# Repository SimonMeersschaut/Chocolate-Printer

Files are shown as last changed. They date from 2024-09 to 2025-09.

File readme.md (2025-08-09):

# Chocolate Printer

## About

This project focuses on modifying a 3D printer to create chocolate sculptures. Achieving this required changes to both the hardware and software. This repository contains all the information you need to replicate the setup yourself.

## Documentation

For extensive documentation, please refer to the pdf file `documentation/main.pdf`. We chose not to include this file in the source code, so you will have to compile the pdf yourself.

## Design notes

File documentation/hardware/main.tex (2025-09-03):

\subsection{Stepper Motor}

\begin{tabular}{@{}ll}
    \textbf{Type:} & Creality CR - M4 42-34 Motor \\
    \textbf{Voltage:} & Max 1A \\
    \textbf{Current Range:} & Ideally 0.9A - 1.2A (Motor cracking sound below this range) \\
    \textbf{Current Range:} & 0.3A to 2.5A (Source: \url{https://www.youtube.com/watch?v=7spK_BkMJys}) \\
    \textbf{Holding Torque:} & 2.86 kg.cm Type \\
\end{tabular}

\subsection{Stepper Motor Driver}

\textbf{Old Stepper Motor Driver}

\begin{tabular}{@{}ll}
    \textbf{Type:} & A4988 \\
    \textbf{Recommended Current:} & Max 1A \\
    \textbf{Microstepping:} & \\
\end{tabular}

\noindent
\textbf{New Stepper Motor Driver}

\begin{tabular}{@{}ll}
    \textbf{Type:} & TMC2208? \\
\end{tabular}

% \includegraphics[width=0.7\textwidth]{image.png}

\subsection{Arduino CNC Shield}

\begin{tabular}{@{}ll}
    \textbf{Type:} & Arduino Mega CNC shield: RAMPS 1.4  \\
    \textbf{Url:} & \url{https://www.manomano.fr/p/3d-controleur-dimprimante-ramps-14-mega-shield-pour-arduino-reprap-prusa-mendel-86220892} \\
    \textbf{Docs:} & \url{https://reprap.org/wiki/RAMPS_1.4}
\end{tabular}

In order to run pn 24 volt, you have to disconnect the board from the ardiono Mega by removing a diode.
This is explained in detail here: \url{https://reprap.org/wiki/RAMPS_24v}.

\subsection{Temperature Sensor}

\textbf{Type:} NTC 10K, B57164 - K103 - K

\textbf{Resistance Values:}
\begin{itemize}
    \item 25$^\circ$C: Approximately 6,000 Ohm
    \item 50$^\circ$C: Approximately 2,000 Ohm (Target: 1,000 Ohm).  A parallel resistor of 2 kOhm is needed.
\end{itemize}

\subsection{Leadscrew, Nut, and Coupler}

\textbf{Nut:} \url{https://www.123-3d.nl/123-3D-Leadscrew-moer-TR8x8-i1560-t9712.html}

\textbf{Coupler:} \url{https://www.123-3d.nl/123-3D-Flexibele-motor-koppeling-5-mm-8-mm-i342-t3045.html}

\textbf{Leadscrew:} \url{https://www.123-3d.nl/123-3D-Leadscrew-TR8x8-8-mm-30-cm-i1558-t9712.html}

\textbf{Heating Wire:} \url{https://www.amazon.com.be/-/en/Meter-Silicone-Rubber-Heating-Electric/dp/B0CD1BSY5F?th=1}

\textbf{Thermistor:} \url{https://www.amazon.com.be/-/en/Thermistors-Resistors-Sensitivity-Temperature-Measurement/dp/B0CH1CC1S6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}

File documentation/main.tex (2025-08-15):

\documentclass{article}
\usepackage[utf8]{inputenc}
\usepackage{graphicx}
\usepackage{url}
\usepackage{titling}
\usepackage[a4paper,margin=2cm]{geometry} % Added for smaller margins

\usepackage{array}
\usepackage{tabularx}
\usepackage{titlesec}
\usepackage{graphicx}
\usepackage{multicol}
\usepackage{fancyhdr}
\usepackage{longtable}

\usepackage{pdfpages} % For including 3d drawings

% Add spacing between sections and paragraphs
\usepackage{titlesec}
\titlespacing*{\section}{0pt}{2.8ex}{1.4ex}
\titlespacing*{\subsection}{0pt}{5ex}{1.2ex}
\setlength{\parskip}{0.7em}
\setlength{\parindent}{0pt}

\title{Chocolate Printer Documentation}
\author{Simon Meersschaut}
\date{\today}

\begin{document}

\begin{titlepage}
\centering
\vspace*{\fill}
{\Huge \textbf{Chocolate Printer Documentation} \par}
\vspace{1cm}
{\Large Simon Meersschaut \par}
\vspace{0.5cm}
{\Large \today \par}
\vspace*{\fill}
\end{titlepage}

\tableofcontents

\newpage

\section{Introduction}
\input{introduction/main}

\newpage

\section{Hardware}
\input{hardware/main.tex}

\newpage

\section{3D Prints}
\input{3dprints/main.tex}

\newpage

\section{Software}
\input{software/main.tex}

\newpage

\input{experiments/template.tex}

\end{document}

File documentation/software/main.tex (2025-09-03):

\subsection{GRBL software}

GRBL is an open source software that runs on an Arduino.
It accepts commands over the serial port and controls the stepper motors.

See documentation: \url{https://github.com/grbl/grbl}

\subsection{G200: Get buffer size}

We modified GRBL to accept a new G200 command.
When the controller receives a G200 command, it responds
with \verb|$G200=...| where \verb|...| is the amount of commands in the
buffer (that is, received commands that are not executed yet).
This way, our controller knows where in the execution the Arduino
currently is.

\subsection{M104: Set extruder and syringe temperatures}

We extended the \verb|M104| command to accept comma-separated tool--temperature tuples.  
The format is:

\begin{verbatim}
M104 T0:<temp>,T1:<temp>
\end{verbatim}

For example:
\begin{verbatim}
M104 T0:200,T1:180
\end{verbatim}

This sets the extruder (T0) to 200~°C and the syringe (T1) to 180~°C.  
Each tool index corresponds to a heater/thermistor pair in the firmware.  
If only one tuple is provided, only that tool's target temperature is updated.

\subsection{M105: Get extruder and syringe temperatures}

When the gcode sender sends \verb|M105|, the GRBL controller responds
with the current temperatures of all tools in the same tuple format:

\begin{verbatim}
$M105=T0:199.873,T1:180.122
\end{verbatim}

This makes it easy to monitor multiple heaters simultaneously.

\subsection{Temperature control}

The temperature can be set and monitored with the commands mentioned above.
In the source code of the controller, we added a file \verb|temperature.c| which
handles heating and temperature measurements. On every update cycle, the Arduino
reads the current temperature from each thermistor and decides whether the
corresponding heater should be switched on or off based on the target temperature.
This forms a simple bang-bang controller for each heater.

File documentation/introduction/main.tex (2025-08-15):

\subsection{Abstract}

This project focuses on modifying a 3D printer to create chocolate sculptures.
Achieving this required changes to both the hardware and software.

\subsection{Showcase}

\begin{center}
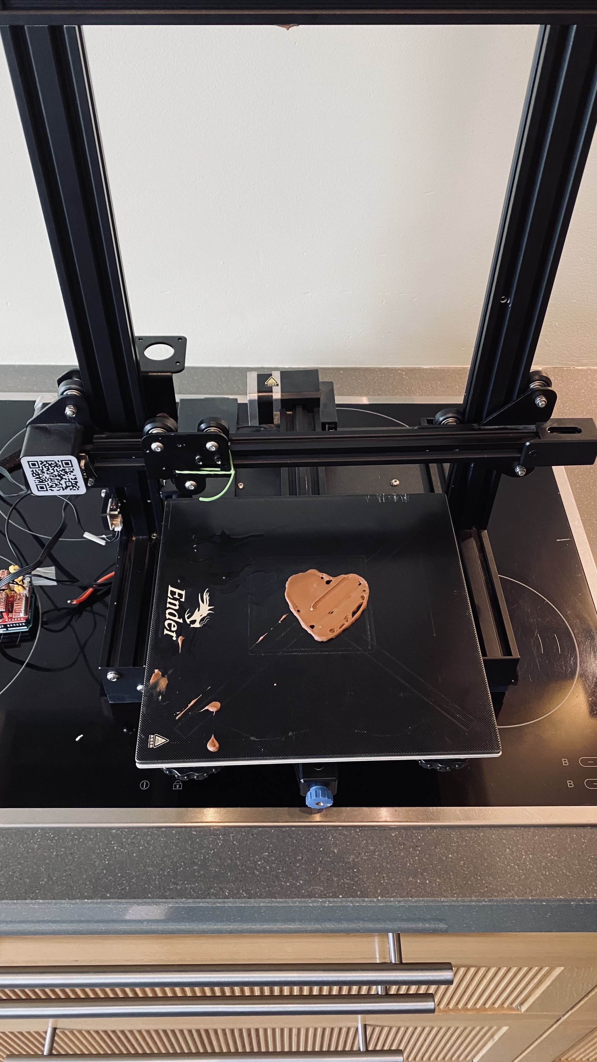
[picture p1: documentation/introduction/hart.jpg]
    
\end{center}

\subsection{Project Overview}

\begin{center}
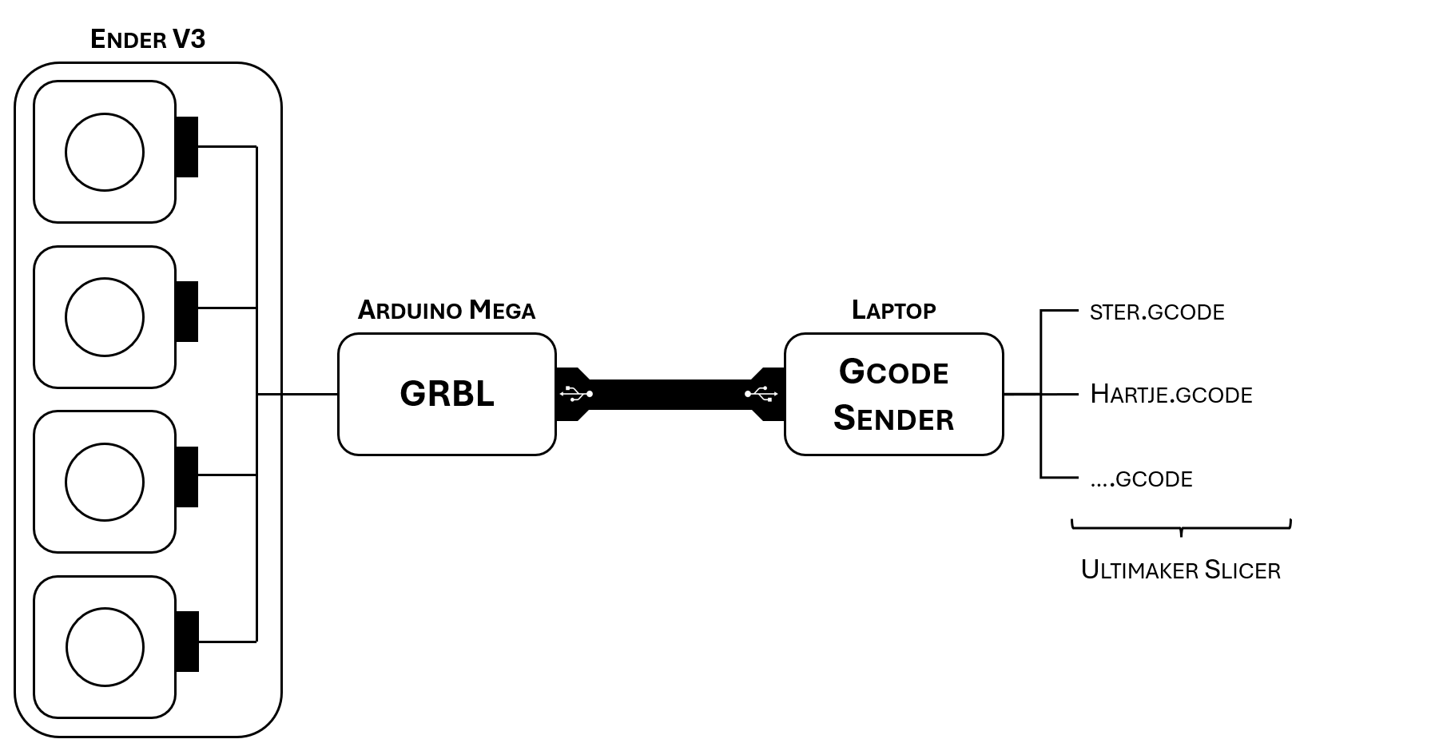
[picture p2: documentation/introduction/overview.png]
    
\end{center}

Herwith I provide a high-level overview of this project.
When you want to print a 3d file, you shall first slice it in a 3d program
like Ultimaker Slicer. After that, you import the .gcode file into the gcode sender.
This is a python Graphical User Interface that communicates with the printer to
monitor its temperature etc. When you press play in the gcode sender, it starts sending
commands to the printer's controller. That is an arduino, running modified GRBL software.
The arduino gets commands like "move to this position at this speed, while extruding this much
chocolate". And finally the arduino will controll its stepper motors so that these commands
are executed.

\newpage % intended for later use

\subsection{Timeline}
To be completed.

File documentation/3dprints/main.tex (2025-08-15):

\subsection{Base}
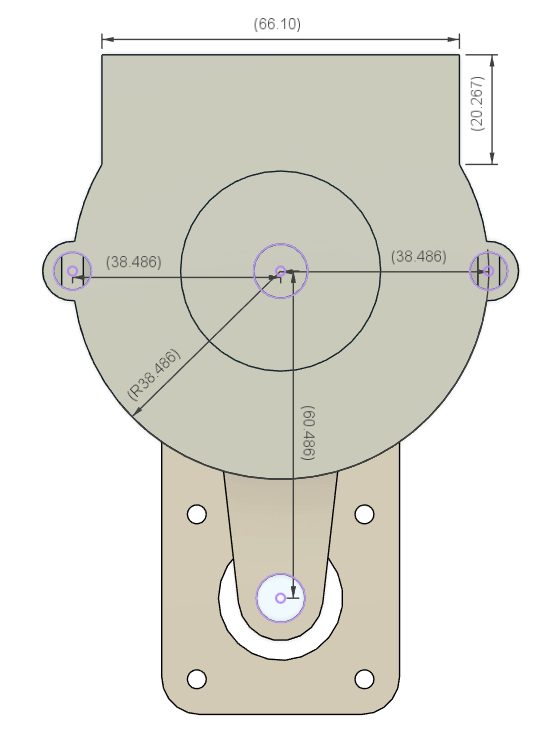
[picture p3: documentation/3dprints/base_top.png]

\includepdf[pages={2}]{3dprints/drawing.pdf}

\subsection{Z-plate}
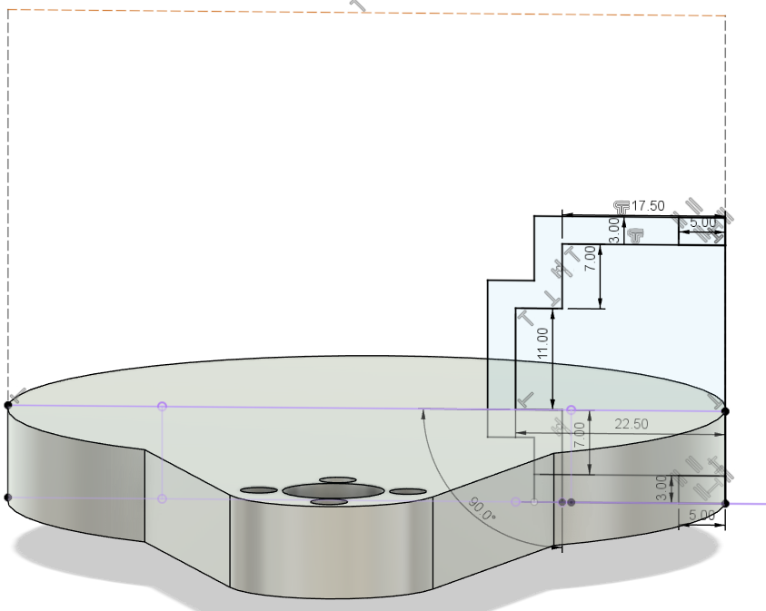
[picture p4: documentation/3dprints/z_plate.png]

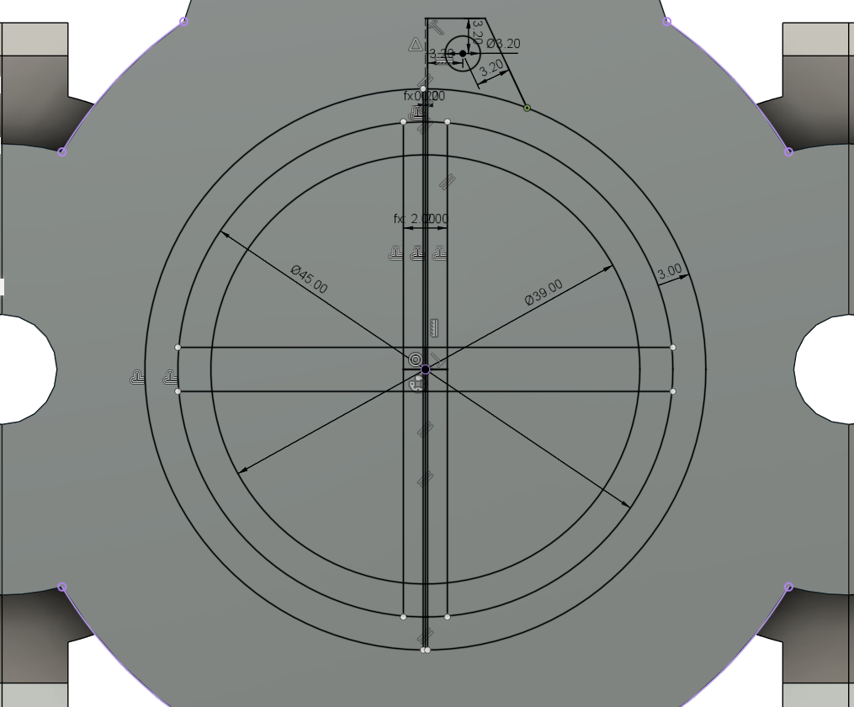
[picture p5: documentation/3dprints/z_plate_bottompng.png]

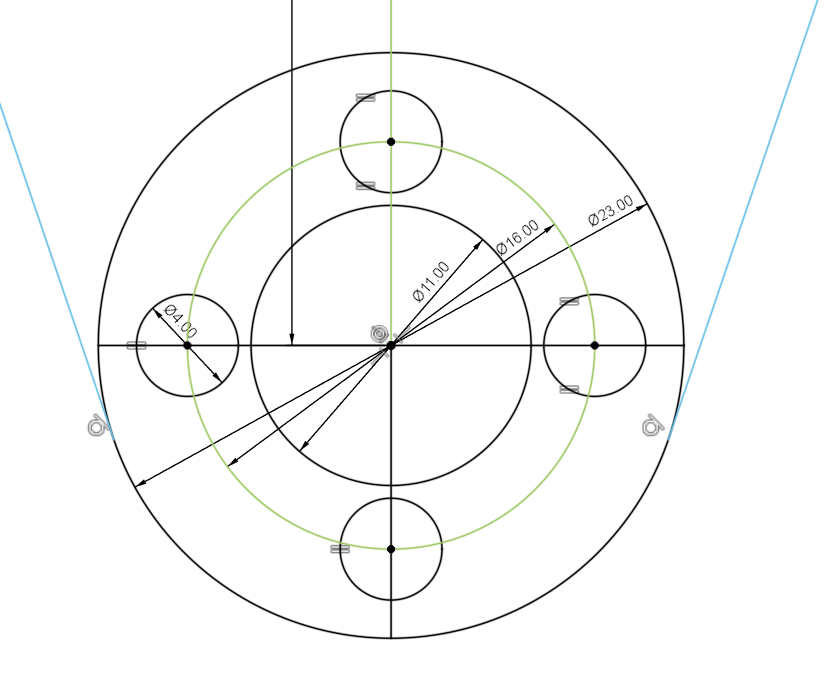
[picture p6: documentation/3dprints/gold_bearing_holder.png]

\includepdf[pages={1}]{3dprints/drawing.pdf}

\subsection{Syringe Holder}
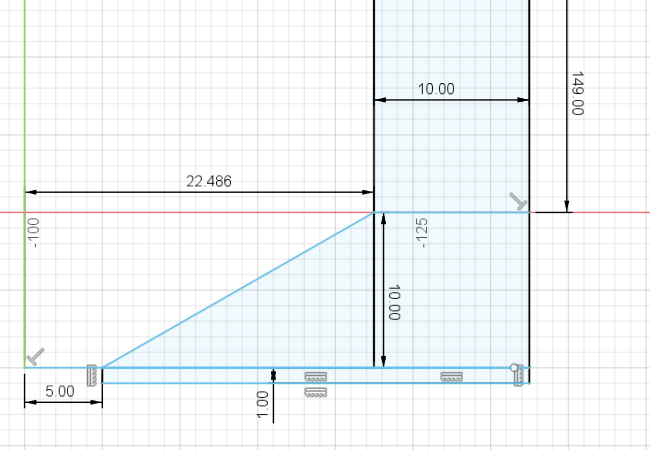
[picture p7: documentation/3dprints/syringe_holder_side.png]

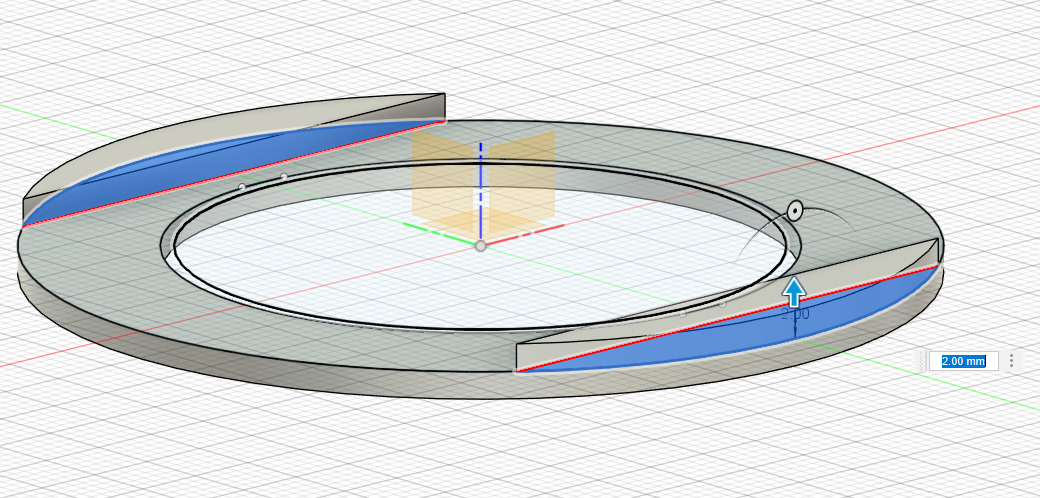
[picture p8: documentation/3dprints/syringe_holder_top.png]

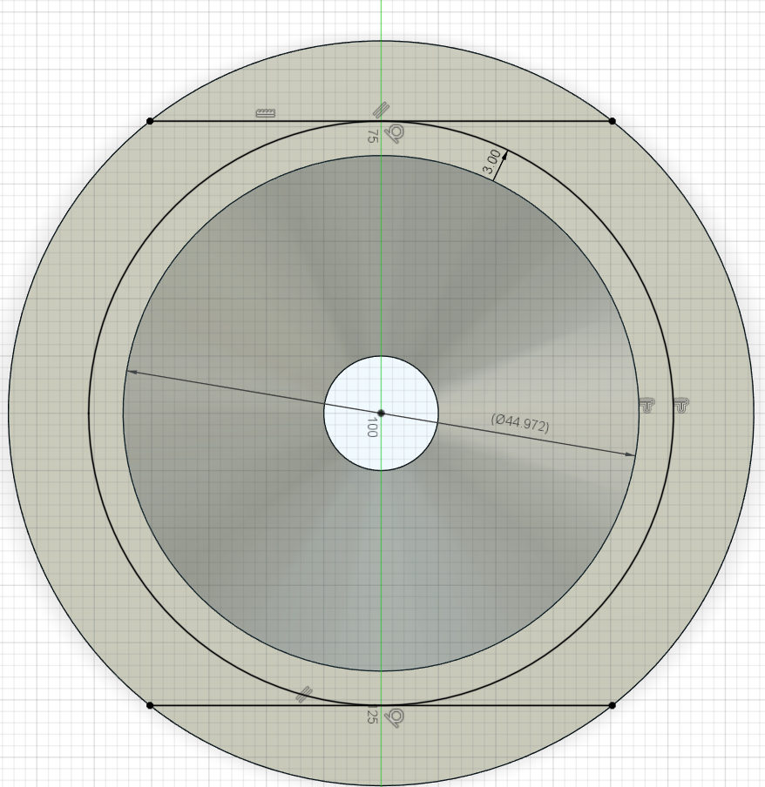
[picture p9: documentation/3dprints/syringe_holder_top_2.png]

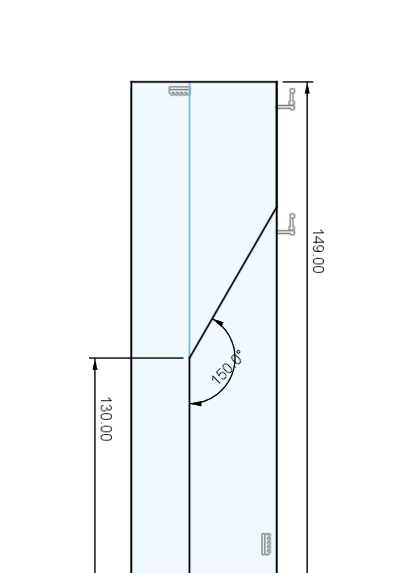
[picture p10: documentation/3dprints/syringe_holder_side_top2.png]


\subsection{Ender Adhesion} % TODO: RENAME FILES
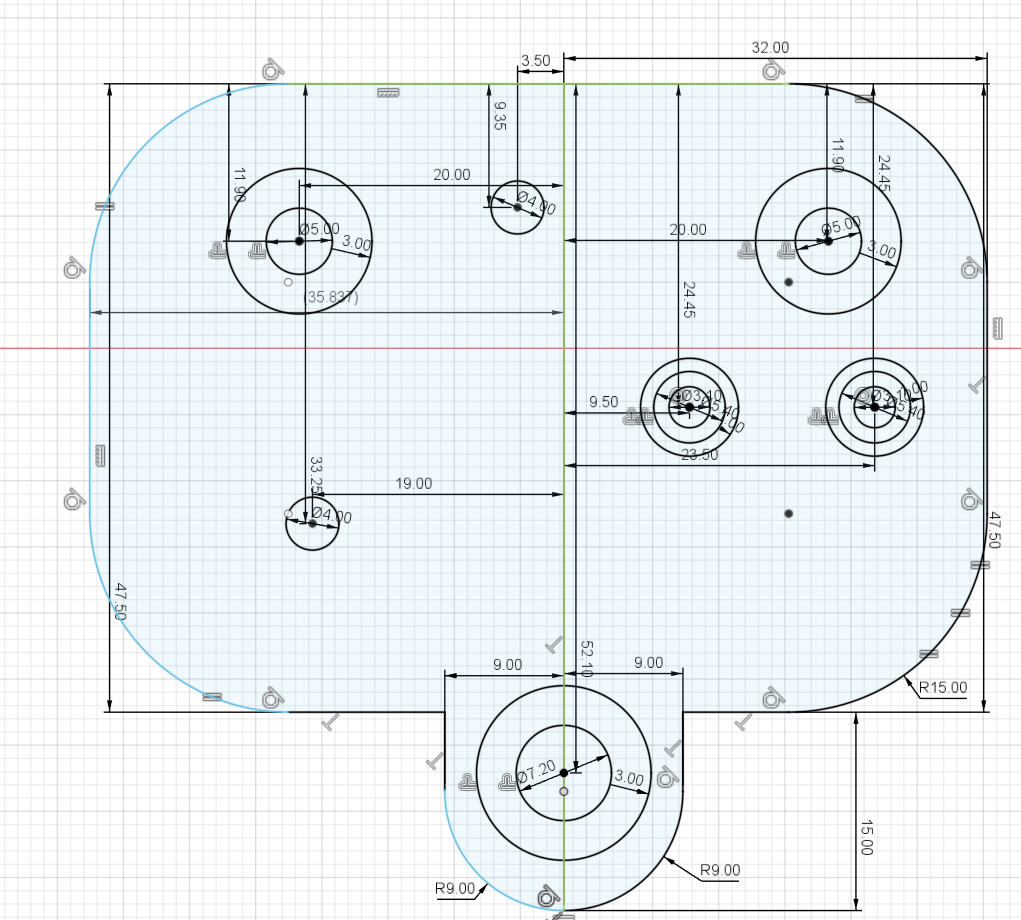
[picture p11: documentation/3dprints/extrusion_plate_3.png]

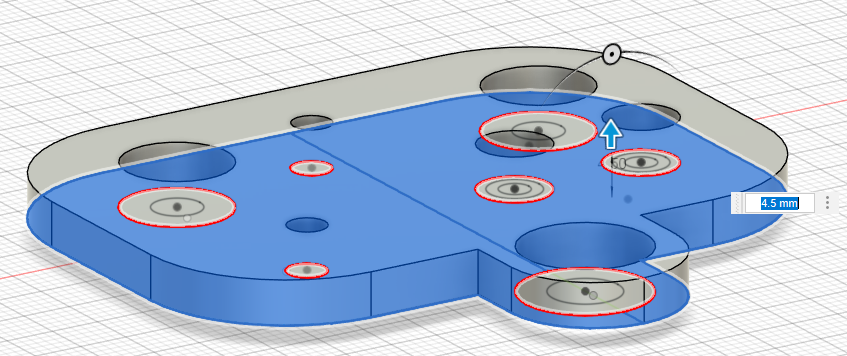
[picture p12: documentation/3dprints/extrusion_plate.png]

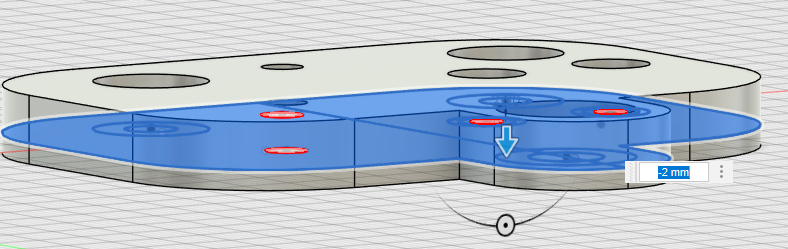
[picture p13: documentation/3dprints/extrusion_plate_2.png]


\subsection{Stepper Motor Adhesion}
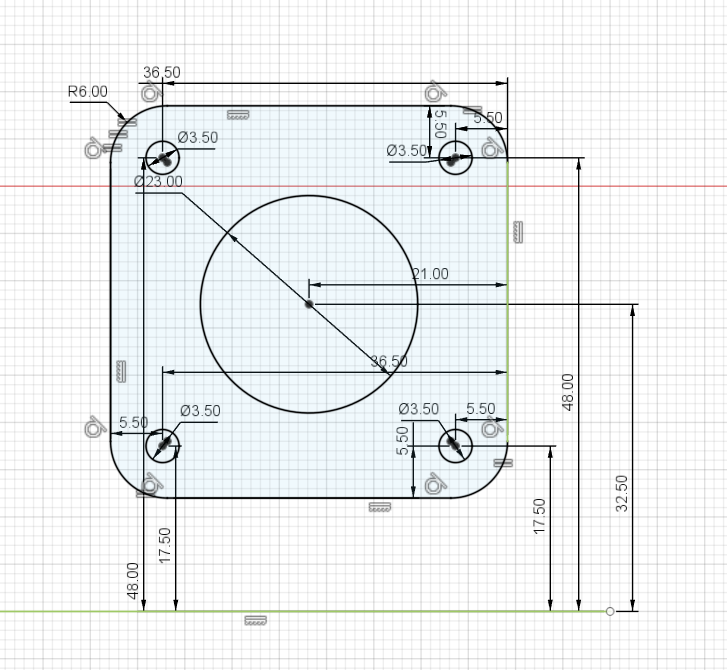
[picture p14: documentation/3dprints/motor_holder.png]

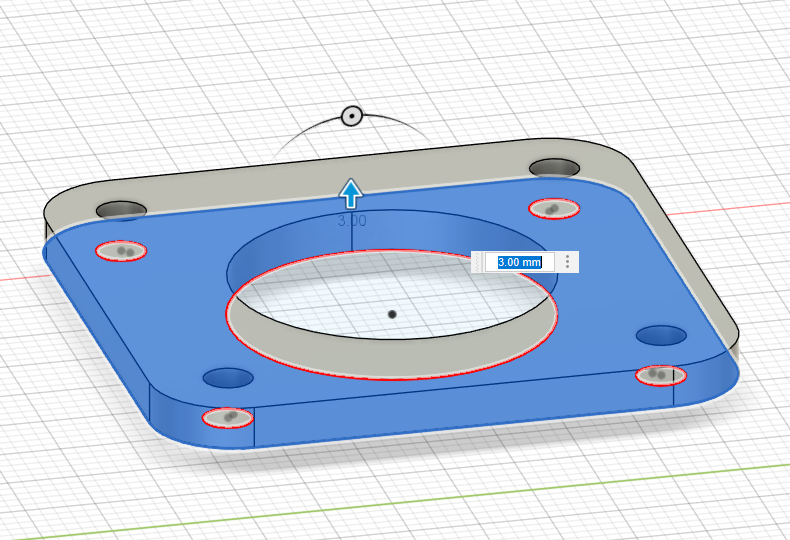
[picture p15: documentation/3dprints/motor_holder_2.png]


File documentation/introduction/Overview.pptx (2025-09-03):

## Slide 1

Ender V3

Arduino Mega

GRBL

Laptop

Gcode Sender

ster.gcode

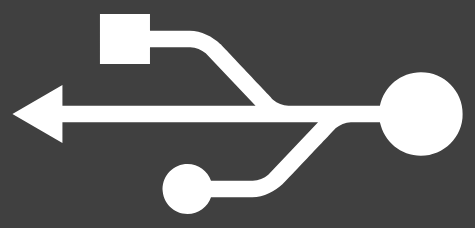
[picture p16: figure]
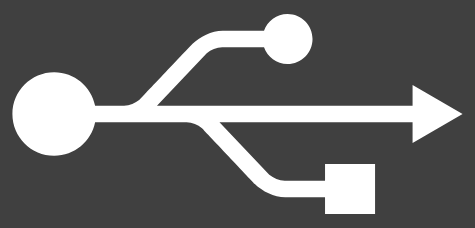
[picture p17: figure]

Hartje.gcode

….gcode

Ultimaker Slicer

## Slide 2

Extruder Heater

T0

T1

Syringe Heater

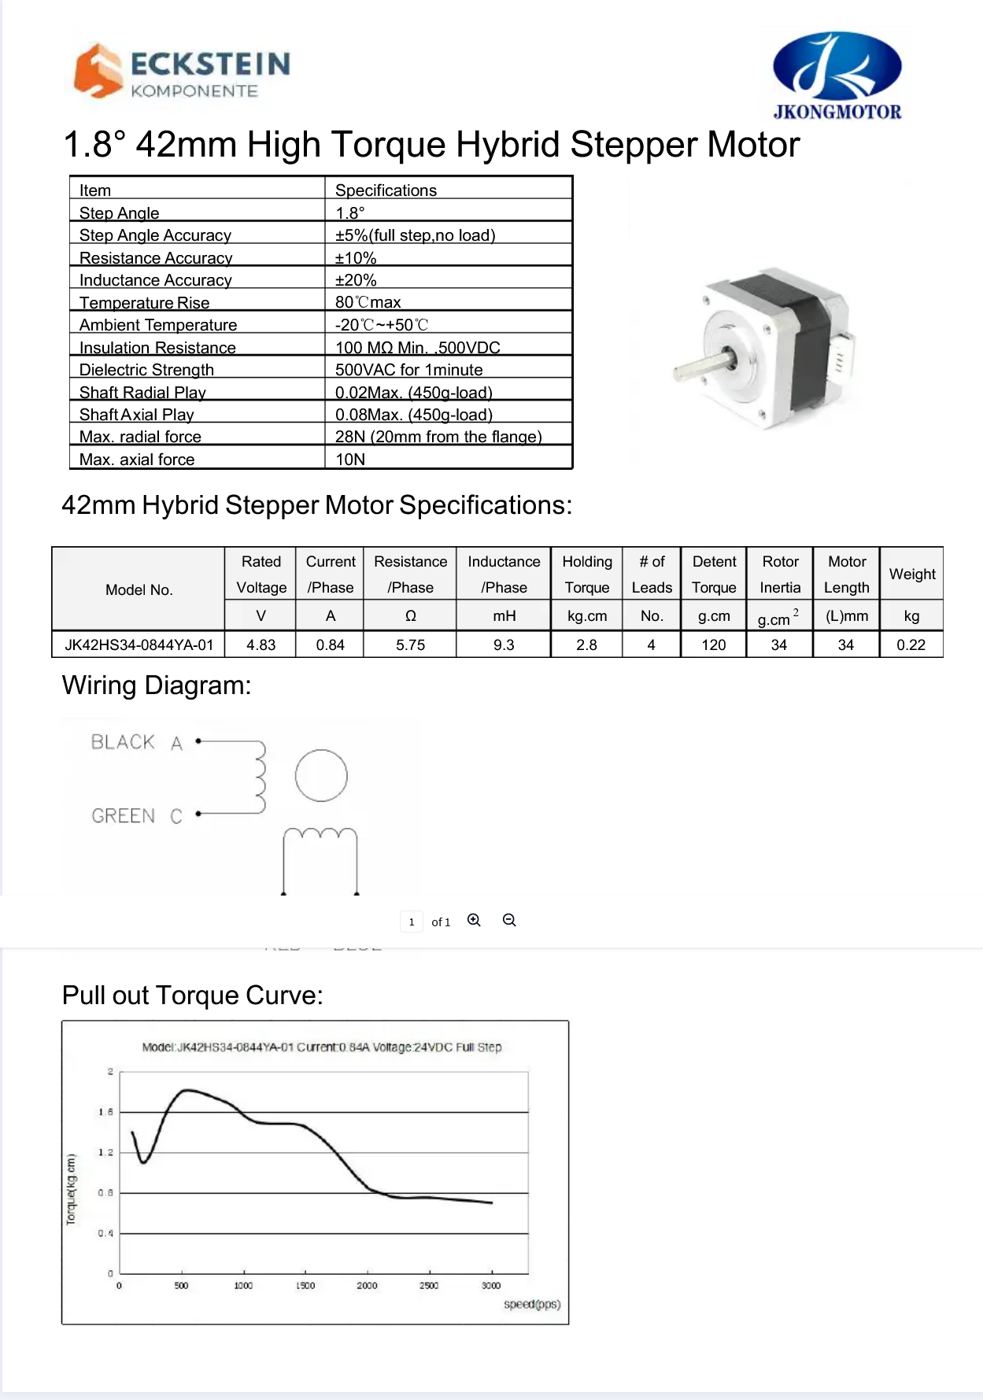
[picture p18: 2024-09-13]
documentation/hardware/stepper_motor/stepper_motor.png

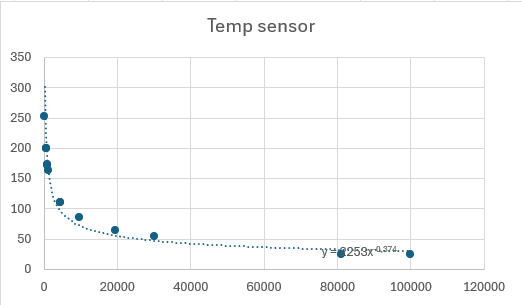
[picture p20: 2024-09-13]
documentation/hardware/thermometer/Temperature sensor.png

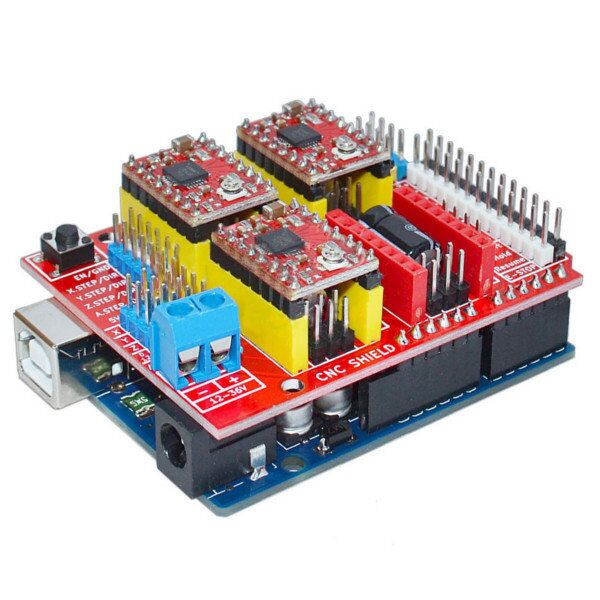
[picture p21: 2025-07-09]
documentation/hardware/arduino_cnc_shield/arduino_cnc_shield.png

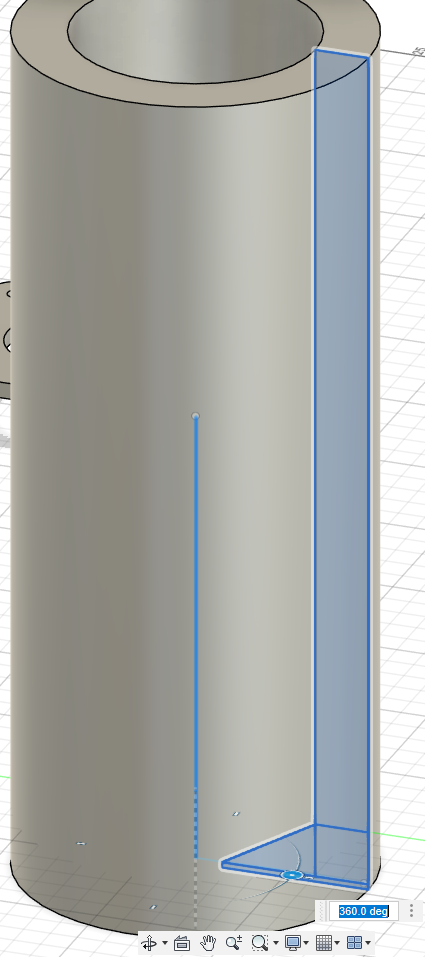
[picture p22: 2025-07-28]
documentation/3dprints/syringe_holder_side_2.png

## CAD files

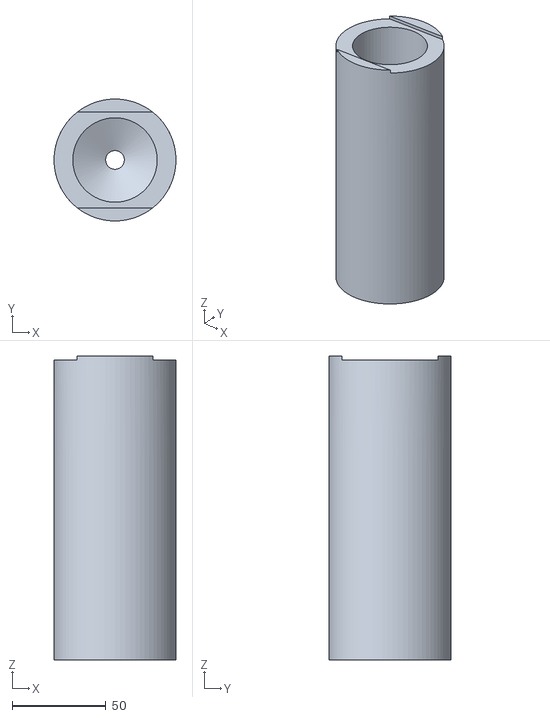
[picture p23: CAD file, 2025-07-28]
documentation/3dprints/spuit-holder-full.stl
65.0 x 65.0 x 162.0

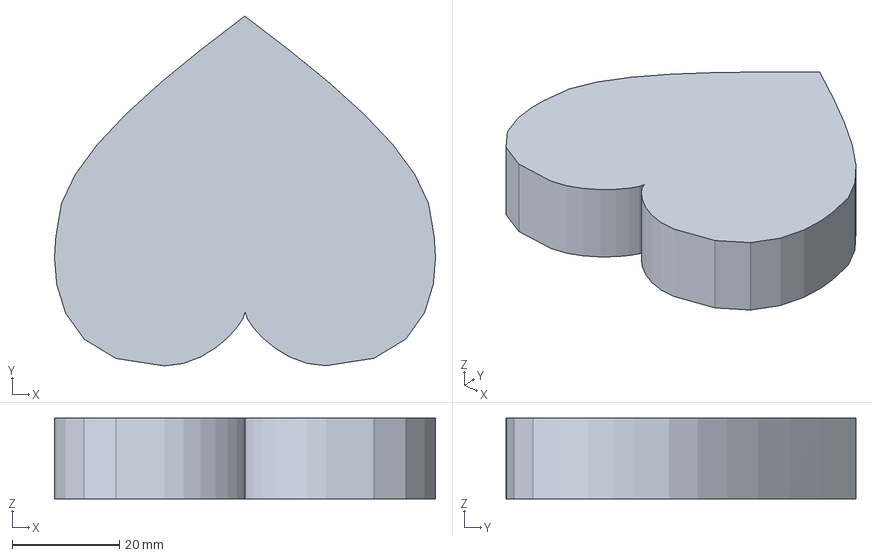
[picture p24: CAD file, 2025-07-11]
3d files/hart/CE3E3V2_v2.3mf
71.0 x 65.2 x 15.0 mm

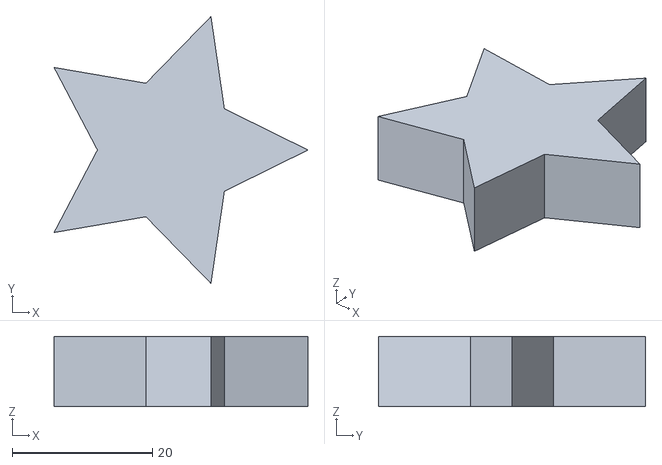
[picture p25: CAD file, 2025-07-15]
3d files/ster/ster.obj
36.2 x 38.0 x 10.0

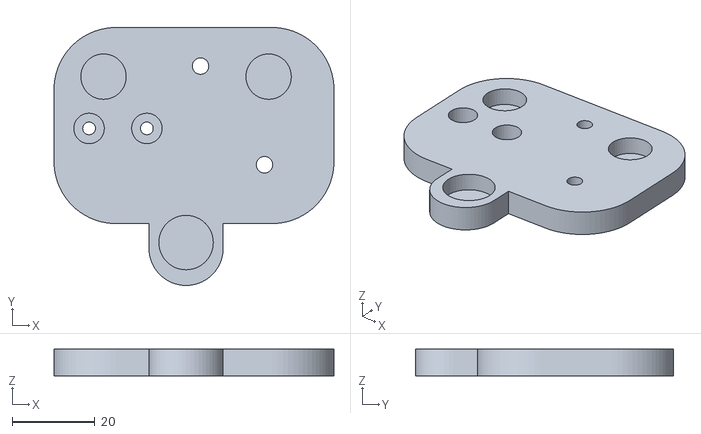
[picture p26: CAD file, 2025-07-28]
documentation/3dprints/Extr-plate-v2.stl
67.8 x 62.5 x 6.50

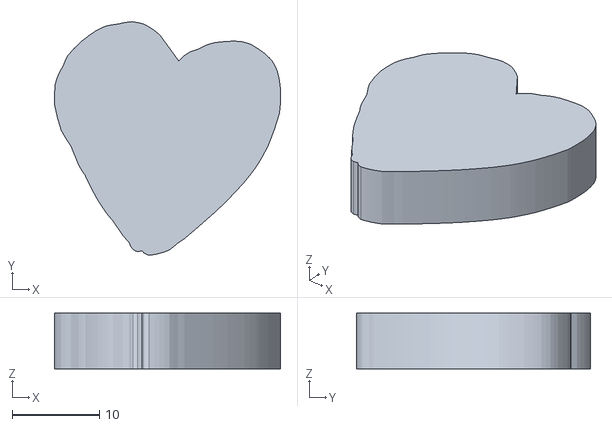
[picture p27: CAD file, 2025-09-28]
model.stl
25.9 x 26.8 x 6.40

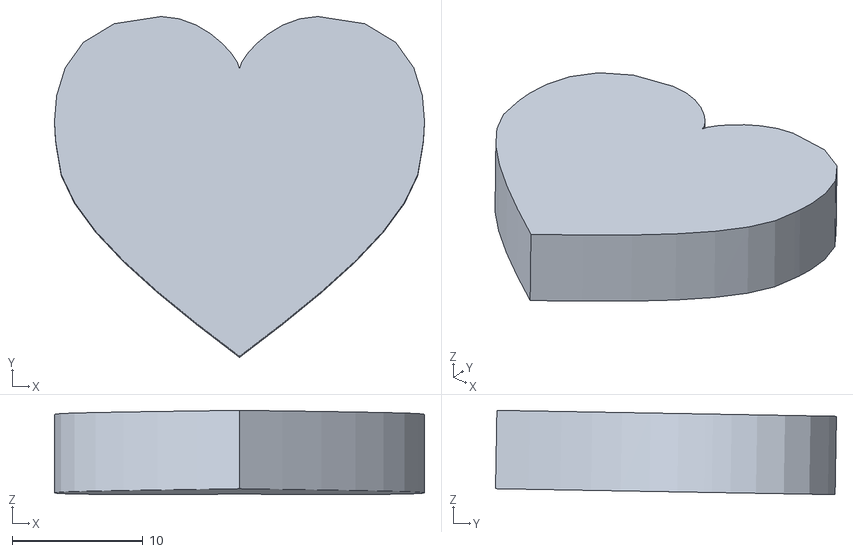
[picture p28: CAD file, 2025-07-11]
3d files/hart/v2.obj
28.3 x 26.1 x 6.45

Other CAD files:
3d files/hart/hart.obj
documentation/hardware/a4998/Chocolate Printer Parts v6.f3d
documentation/hardware/a4998/Chocolate_Extruder_v12_v4.f3d

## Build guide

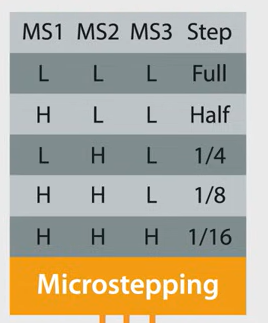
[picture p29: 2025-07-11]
documentation/hardware/a4998/step_sizes.png

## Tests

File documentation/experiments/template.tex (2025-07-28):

\pagestyle{fancy}
\fancyhf{}
\rhead{3D Chocolate Printer Experiment Log}
\lhead{Experiment Entry}
\rfoot{Page \thepage}

\titleformat{\section}{\normalfont\Large\bfseries}{}{0pt}{}

\renewcommand{\arraystretch}{1.4}  % spacing in tables

% \section*{3D Chocolate Printer Experiment Entry}

\noindent
\begin{tabularx}{\textwidth}{>{\bfseries}l X p{3cm}}
Date: & \hrulefill & \hrulefill \\
File Title: & \hrulefill & \hrulefill \\
Bed Temperature (°C): & \hrulefill  & \hrulefill \\
Line Width (mm): & \hrulefill  & \hrulefill \\
Chocolate Temperature (°C): & \hrulefill  & \hrulefill \\
Chocolate Color: & \hrulefill  & \hrulefill \\
Brand: & \hrulefill & \hrulefill \\
Weight of Chocolate (g): & \hrulefill & \hrulefill \\
\end{tabularx}

% \vspace{1cm}

\noindent\textbf{Notes:}

% \vspace{0.3cm}

% Large box for notes (adjust height as needed)
\fbox{%
  \parbox[t][18cm][t]{\textwidth}{%
    \vspace{0.3cm} % Top padding
    \hspace{0.3cm} % Left padding
    \\
    % User writes here
  }%
}

\end{document}

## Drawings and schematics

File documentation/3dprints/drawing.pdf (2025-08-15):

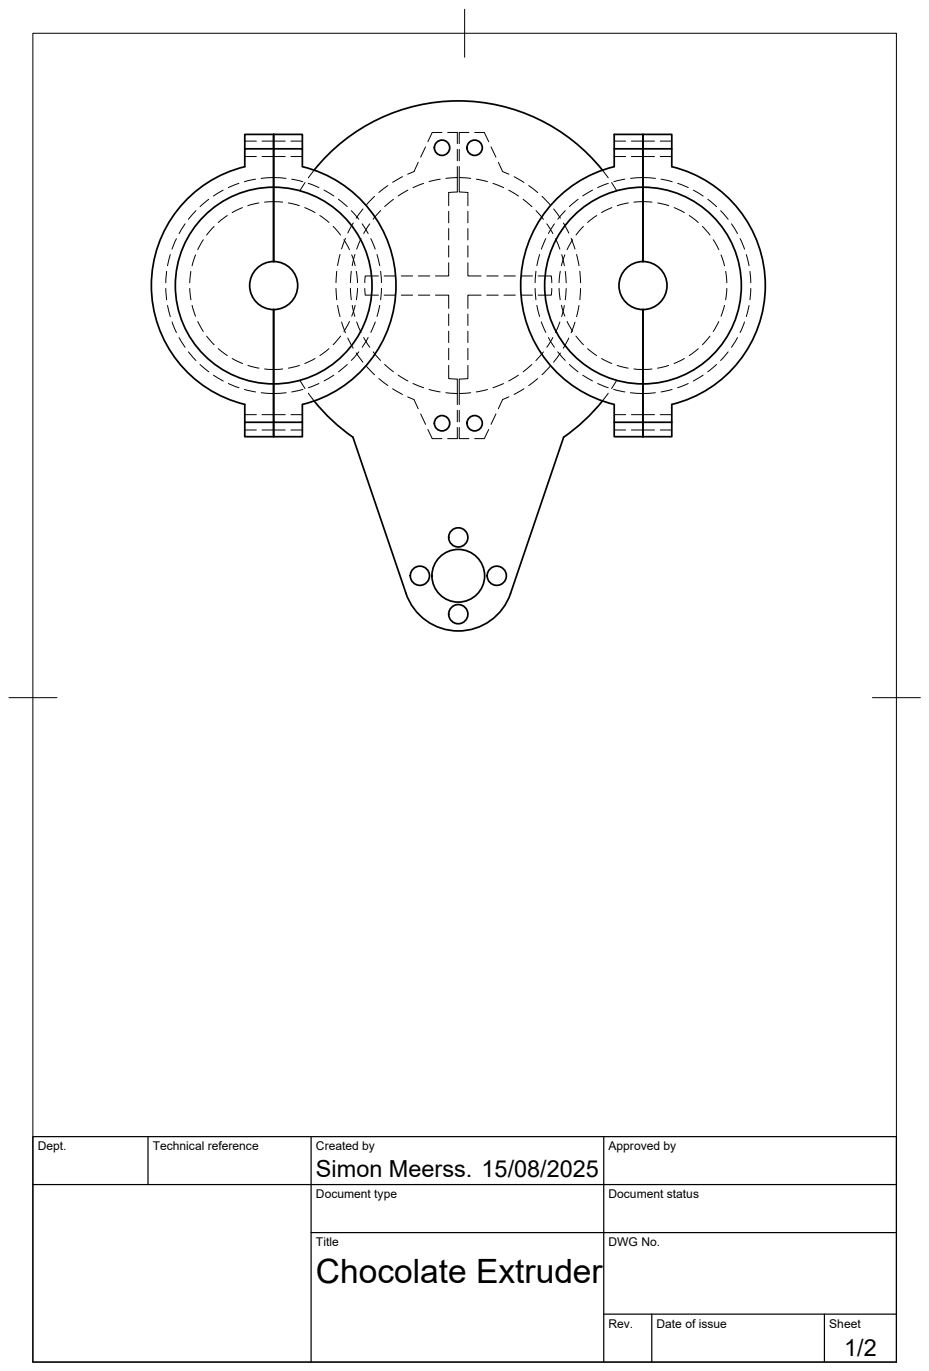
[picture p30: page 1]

Dept. | Technical reference | Created by Simon Meerss. 15/08/2025 | Approved by

Document type | Document status

Title Chocolate Extruder | DWG No.

Rev. | Date of issue | Sheet 1/2

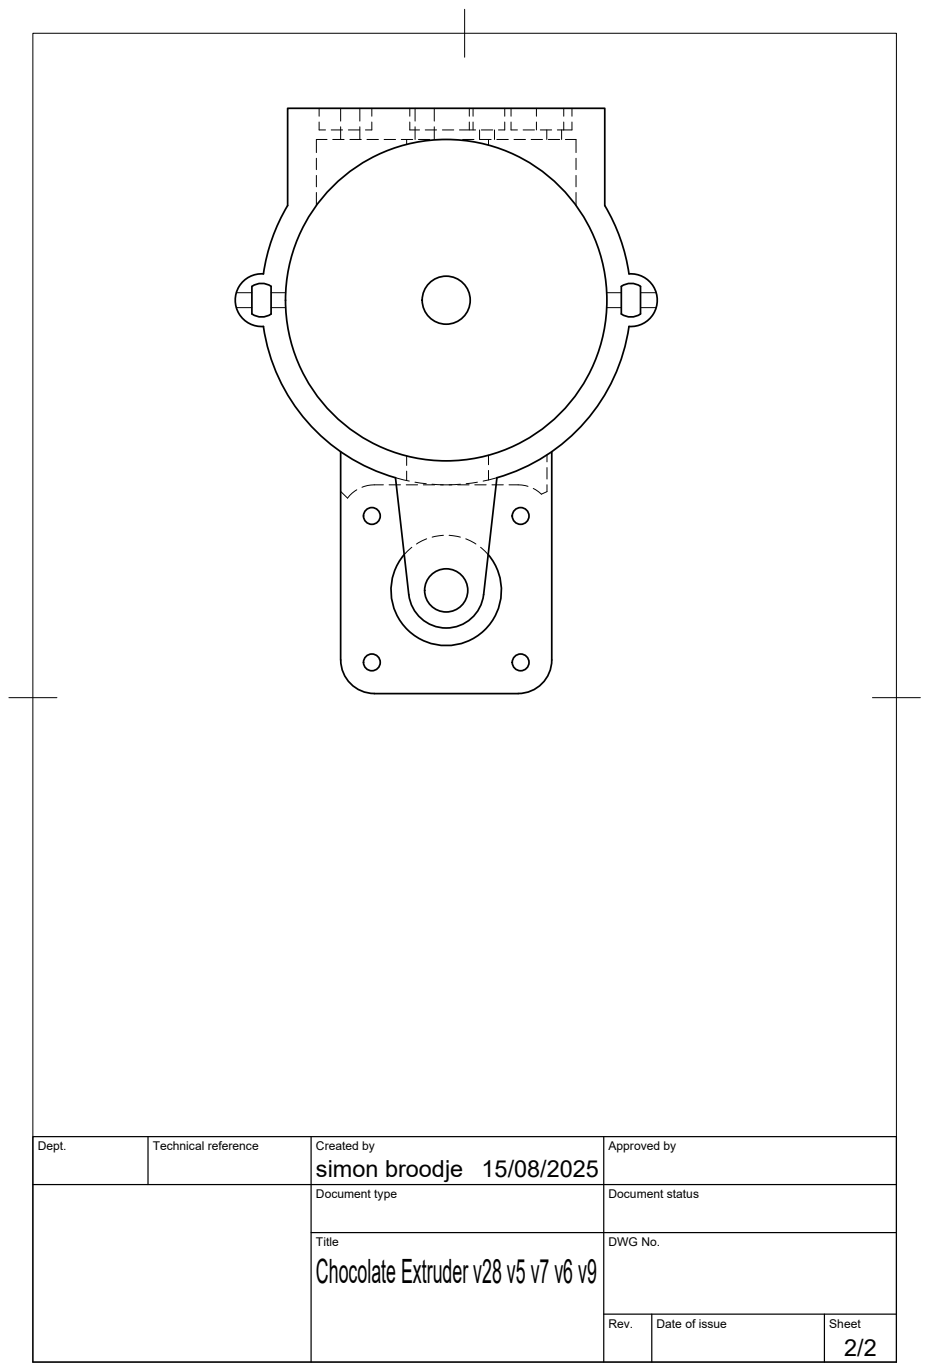
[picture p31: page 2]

Dept. | Technical reference | Created by simon broodje 15/08/2025 | Approved by

Document type | Document status

Title Chocolate Extruder v28 v5 v7 v6 v9 | DWG No.

Rev. | Date of issue | Sheet 2/2

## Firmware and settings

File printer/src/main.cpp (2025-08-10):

/***********************************************************************
This sketch compiles and uploads Grbl to your 328p-based Arduino! 

To use:
- First make sure you have imported Grbl source code into your Arduino
  IDE. There are details on our Github website on how to do this.

- Select your Arduino Board and Serial Port in the Tools drop-down menu.
  NOTE: Grbl only officially supports 328p-based Arduinos, like the Uno.
  Using other boards will likely not work!

- Then just click 'Upload'. That's it!

For advanced users:
  If you'd like to see what else Grbl can do, there are some additional
  options for customization and features you can enable or disable. 
  Navigate your file system to where the Arduino IDE has stored the Grbl 
  source code files, open the 'config.h' file in your favorite text 
  editor. Inside are dozens of feature descriptions and #defines. Simply
  comment or uncomment the #defines or alter their assigned values, save
  your changes, and then click 'Upload' here. 

Copyright (c) 2015 Sungeun K. Jeon
Released under the MIT-license. See license.txt for details.
***********************************************************************/

#include <grbl.h>

// do not alter this file

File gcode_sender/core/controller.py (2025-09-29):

import time
from .serialBridge import SerialBridge
from .filehandler import GcodeHandler
import events
from logger import NozzleTemperatureWarning
from serial.serialutil import SerialException
import json
import os

class Controller:
    MAX_BUFFER_SIZE = 20
    SERIAL_TIMEOUT = 5  # seconds
    MAX_TEMP_OFFSET = 5  # degrees Celsius
    JOG_DISTANCE = 40  # mm
    RECONNECT_INTERVAL = 5 # seconds

    def __init__(self, logger):
        self.logger = logger
        self.registered_events = []

        self.set_gcode_file("3d files/hart/hart.gcode")
        self.serialBridge = SerialBridge()
        self.is_connected = False
        self.last_reconnect_attempt = 0

        # Track per-tool target & current temperatures
        self.target_temperatures = {"T0": 20, "T1": 20}
        self.current_temperatures = {"T0": 0.0, "T1": 0.0}
    
    def write(self, line: str):
        try:
            return self.serialBridge.write(line + "\r\n")
        except:
            print("Arduino disconnected!")
            self.is_connected = False
            self.serialBridge.is_connected = False
            self.register_event(events.ArduinoDisconnected())

    def flush(self):
        self.serialBridge.flush()

    def readline(self):
        return self.serialBridge.readline().replace("\r\n", "")

    def connect(self):
        try:
            self.serialBridge.connect()
            t_0 = time.time()
            while "Grbl" not in self.serialBridge.readline():
                if time.time() - t_0 > Controller.SERIAL_TIMEOUT:
                    raise RuntimeError("Timeout")

            self.write("$22=0")  # disable homing

            self.wait_for_ok()

            self.write("$X")
            self.wait_for_ok()

            self.write("$21=0")
            self.wait_for_ok()

            self.write("$3=4")  # invert Z axis
            self.wait_for_ok()

            self.write("G21")  # mm
            self.wait_for_ok()
            self.write("G90")  # absolute coords
            self.wait_for_ok()

            self.is_connected = True
            self.serialBridge.is_connected = True
            self.register_event(events.ArduinoConnected())
            self.send_settings_from_file()
        except (RuntimeError, SerialException):
            self.is_connected = False
            self.serialBridge.is_connected = False
            self.register_event(events.ArduinoDisconnected())

    def set_heating(self, tool: str, temperature: int):
        """Set target temperature for a specific tool (e.g., T0, T1)."""
        self.target_temperatures[tool] = temperature
        # Send full tuple (all tools), so firmware always has consistent state
        cmd_parts = [f"{t}:{temp}" for t, temp in self.target_temperatures.items()]
        cmd = ",".join(cmd_parts)
        self.write(f"M104 {cmd}")
        self.wait_for_ok()

    def update(self):
        if not self.is_connected:
            if time.time() - self.last_reconnect_attempt > self.RECONNECT_INTERVAL:
                self.last_reconnect_attempt = time.time()
                self.connect()
            return [] # No updates if not connected

        try:
            self.serialBridge.flush()

            # Update buffer size bookkeeping
            if self.gcode_handler.aprox_buffer >= Controller.MAX_BUFFER_SIZE:
                cpy = self.gcode_handler.aprox_buffer
                self.gcode_handler.aprox_buffer = self.get_aprox_buffer()
                self.gcode_handler.execution_line += max(0, cpy - self.gcode_handler.aprox_buffer)
                self.register_event(events.SetGcodeLine(self.gcode_handler.execution_line))

            # Feed commands
            if self.gcode_handler and self.gcode_handler.playing:
                if self.gcode_handler.com_line < self.gcode_handler.get_size():
                    t_0 = time.time()
                    while self.gcode_handler.aprox_buffer < Controller.MAX_BUFFER_SIZE:
                        if time.time() - t_0 > Controller.SERIAL_TIMEOUT:
                            raise RuntimeError("Timeout")
                        if self.gcode_handler.com_line >= self.gcode_handler.get_size():
                            break
                        else:
                            command = self.gcode_handler.get_line(self.gcode_handler.com_line)
                            if (
                                len(command) == 0
                                or command[0] == ";"
                                or command[0] == "M"
                                or command[0:3] == "G92"
                            ):
                                self.gcode_handler.execution_line += 1
                            else:
                                self.write(command + "")
                                self.wait_for_ok()
                                self.gcode_handler.aprox_buffer += 1
                            self.gcode_handler.com_line += 1

            # Request temperatures
            self.write("M105")
            t_0 = time.time()
            while True:
                if time.time() - t_0 > Controller.SERIAL_TIMEOUT:
                    raise RuntimeError("Timeout")
                line = self.serialBridge.readline()
                if "ok" == line:
                    continue
                elif "$M105=" in line:
                    # Parse tuple response: $M105=T0:200.000,T1:180.000
                    payload = line.split("=")[-1].strip()
                    pairs = payload.split(",")
                    for pair in pairs:
                        tool, val = pair.split(":")
                        self.current_temperatures[tool] = float(val)
                    break

            # Safety check for each tool
            for tool, target in self.target_temperatures.items():
                current = self.current_temperatures.get(tool, 0.0)
                if abs(target - current) > Controller.MAX_TEMP_OFFSET:
                    self.logger.show_message(NozzleTemperatureWarning(tool))
                self.register_event(events.UpdateNozzleTemperature(tool, current))

            self.serialBridge.flush()

        except (SerialException, RuntimeError) as e:
            print(f"Error: {e}")
            self.is_connected = False
            self.serialBridge.is_connected = False
            self.register_event(events.ArduinoDisconnected())
        
        finally:
            cpy = self.registered_events
            self.registered_events = []
            return cpy

    def register_event(self, event: events.Event):
        self.registered_events.append(event)
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

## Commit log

2025-07-09 add grbl code
2025-07-11 Add 3d models
    [CE3E3V2_v2.3mf, hart.obj, v1.obj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]
2025-07-15 Move Java files to other repo
    [ster.obj]
2025-07-25 Download grbl5x
2025-07-28 Add latex documentation
    [Chocolate Printer Parts v6.f3d, Chocolate_Extruder_v12_v4.f3d]
2025-07-28 Add 3d prints documentation
    [Extr-plate-v2.stl, spuit-holder-full.stl]
2025-07-28 Add docs
    [default_config.txt]
2025-07-28 Add docs for grbl software
2025-07-29 Add Dash website
    [default_config.txt]
2025-07-29 Rework GUI in Tkiner
    [controller.py, serialBridge.py]
2025-08-03 Add jog buttons
2025-08-09 Switch to Arduino Mega
2025-08-10 Read nozzle temperature
2025-08-14 Add target temperature updates
2025-08-15 Add open file button
2025-08-16 Update gcode sender
    [v1.obj]
2025-09-03 Add extruder temperature control
2025-09-28 Set Extruder settings
    [model.stl]
2025-09-29 Added GRBL settings (not finished yet)
